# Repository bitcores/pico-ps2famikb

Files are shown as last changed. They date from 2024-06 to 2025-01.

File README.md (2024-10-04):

# pico-usb2famikb
Raspberry Pi Pico driven multi device emulator and Keyboard and Mouse Host for Famicom/NES by direct USB input or with an i2c host device

Emulates
* Family Basic Keyboard
* Subor Keyboard and Mouse
* Hori Track

And supports Keyboard and Mouse Host mode, a community developed serialized keyboard and mouse interface.

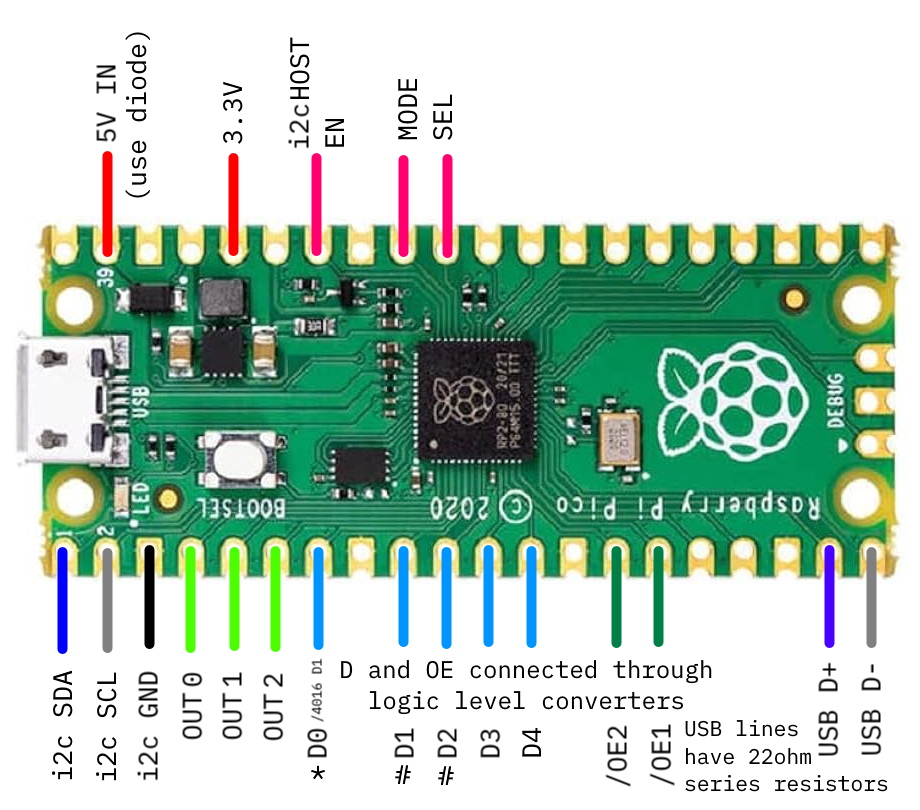
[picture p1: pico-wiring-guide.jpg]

- \* D0 is only needed for subor mouse support. Connecting it will conflict with controller 2, it can be left disconnected. 4016 D1 shares this pin, it is only needed for Hori Track support on Famicom.
- \# D1 and D2 are only needed for Family Basic Keyboard mode, these can be left disconnected (esp. if making for NES player 2 controller port)
- \? USB D+ and D- lines are only needed for direct input. These can be left disconnected if only the i2c Host will be used (i2c Host EN can then be tied to 3.3V to permanently enable it)
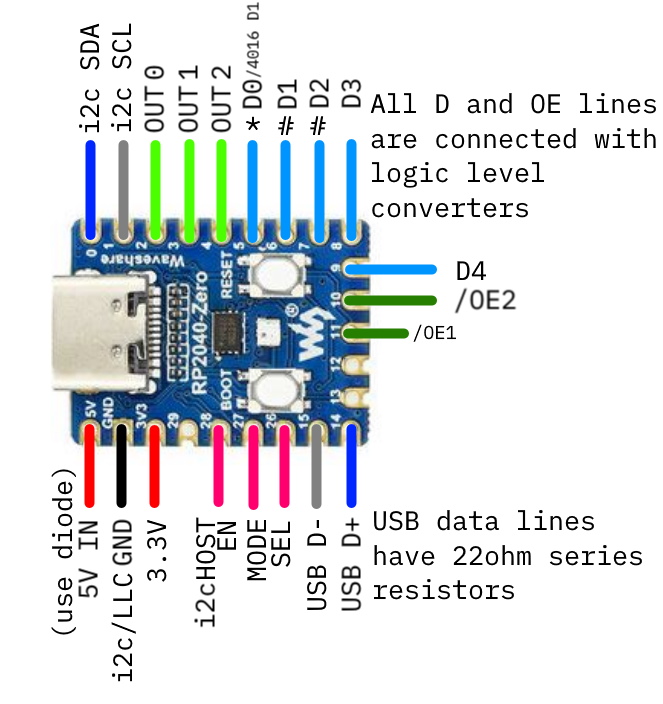
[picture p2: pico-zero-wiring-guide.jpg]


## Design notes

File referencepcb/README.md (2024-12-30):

# pico-usb2famikb Reference PCBs
This directory contains reference PCB designs for the pico-usb2famikb. They have not been designed by a experienced engineer, but they DO work.

If you have some experience designing circuits like this, I would very much welcome improved designs.

For the full featured reference design you will need:
* 1x Raspberry Pi Pico
* 1x diode (I am using a 1N5819)
* 1x push button
* 1x 15pin d-sub VGA connector (for expansion port)
* 1x USB A type female port
* 2x 22ohm resistors
* 1x 100uf 16v capacitor (input from console)
* 1x 330uf 16v capacitor
* 2x four-channel logic level converters
* 13x pin headers (and some jumpers)

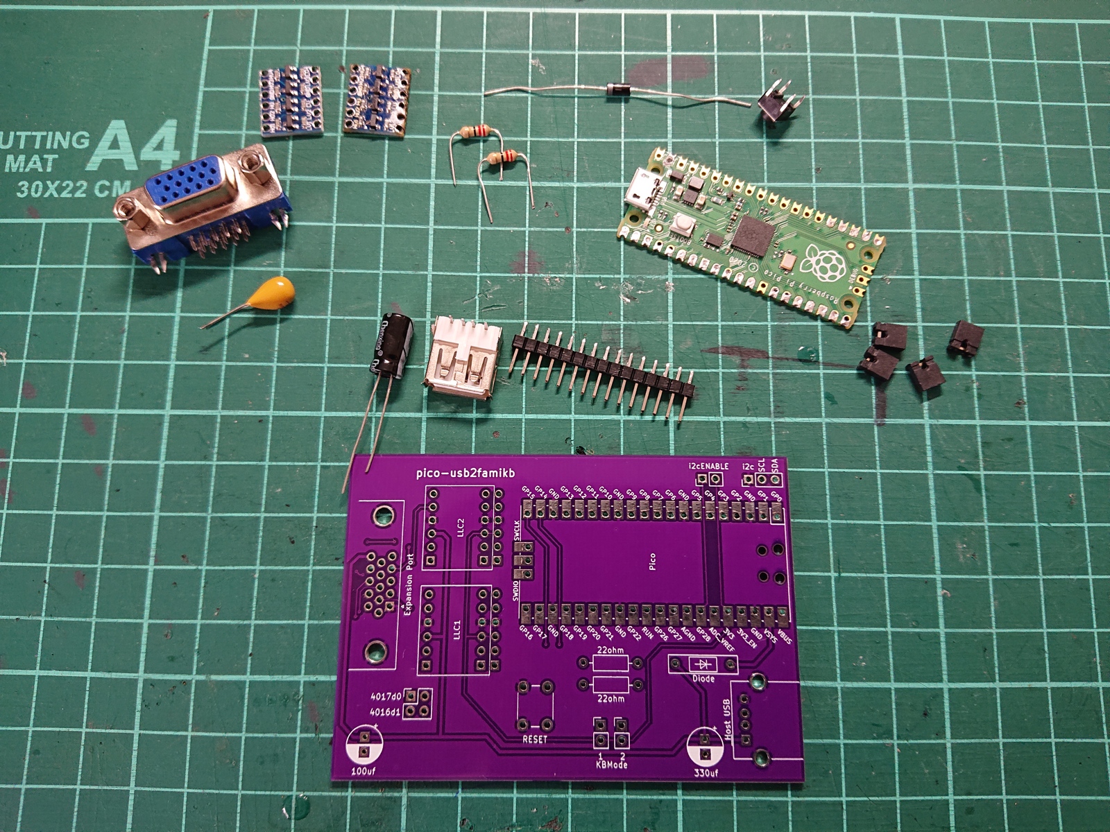
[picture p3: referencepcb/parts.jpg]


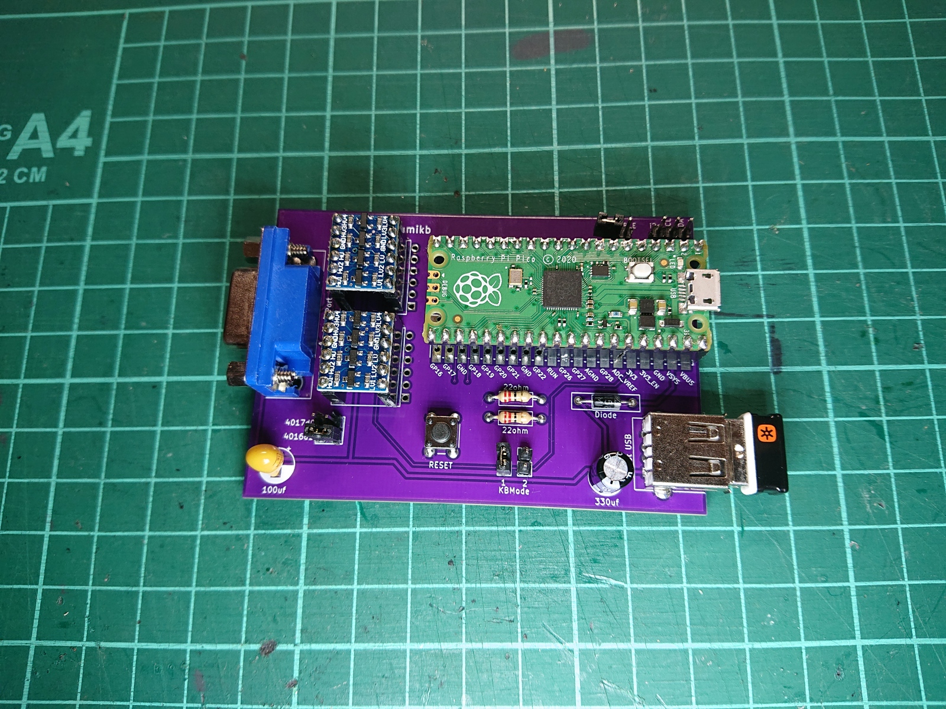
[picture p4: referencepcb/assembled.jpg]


Note: The 330uf capactior was added because some USB3 hubs seem to draw significant power on startup can could crash the console or Pico, or both. The USB2 hubs I tested don't seem affected, but you can also just plug everything in before you turn on the console to avoid any issues.

## Wiring guide
The expansion port connector is laid out as follows when viewed from the top.

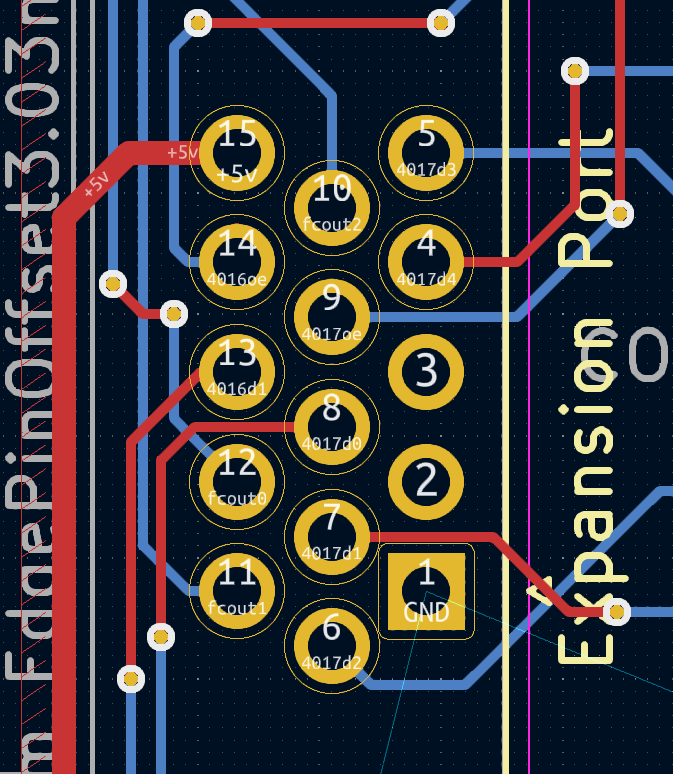
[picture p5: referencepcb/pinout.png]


It is wired following the pinout of the [Famicom Expansion Port](https://www.nesdev.org/wiki/Expansion_port), 01 to 01, 15 to 15.
Wiring for the NES is more complicated, please reference both the tables on that page for wiring.

## Jumper guide
### KB Mode
The pico-usb2famikb can operate in four different modes:
 - Keyboard Mouse Host
 - Family Basic Keyboard
 - Subor Keyboard and Mouse
 - Family Basic Keyboard and HoriTrack

These modes are selected by setting the KBMode jumpers before power on (or reset).

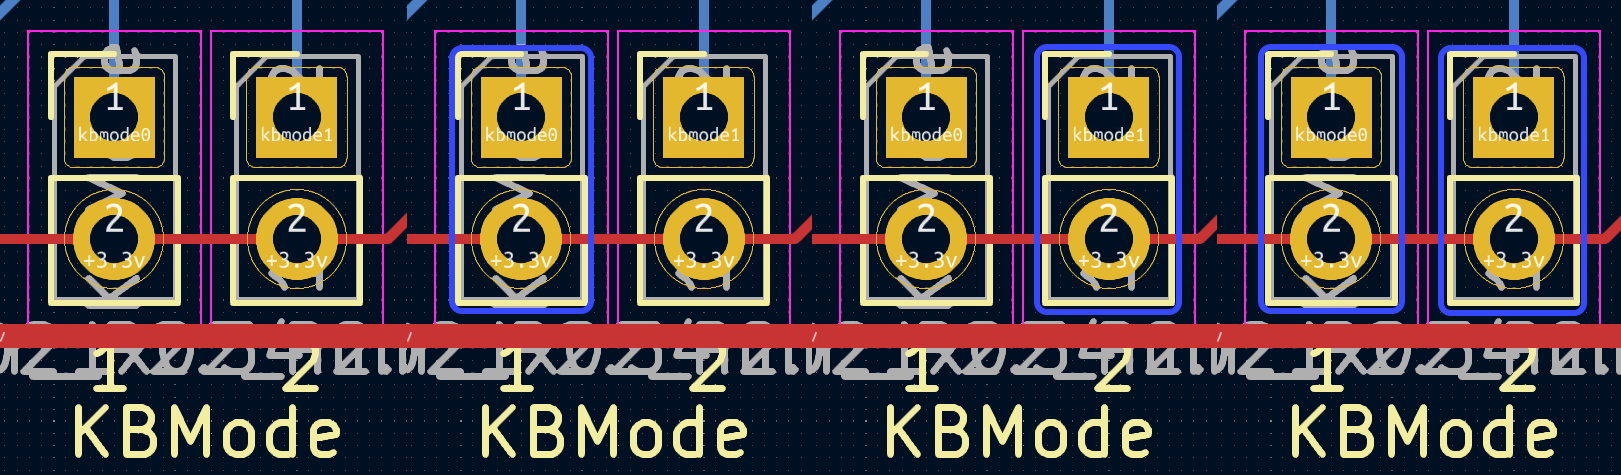
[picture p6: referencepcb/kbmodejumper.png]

 - No jumpers = Keyboard Mouse Host
 - One jumper on KBMode 1 = Family Basic Keyboard
 - One jumper on KBMode 2 = Subor Keyboard and Mouse
 - Two jumpers on KBMode 1 and 2 = Family Basic Keyboard and HoriTrack

### 4016D1/4017D0
HoriTrack and Subor Mouse require an extra data line which may interfere with controllers if left permanantly connected.

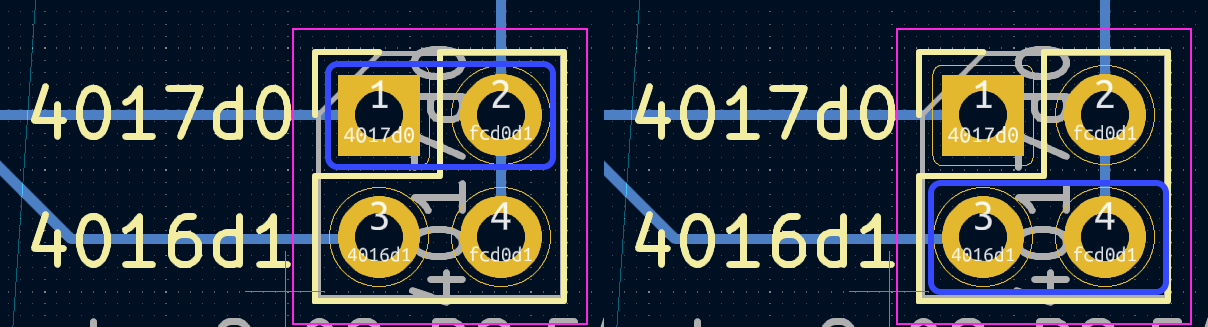
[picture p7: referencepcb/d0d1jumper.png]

 - 4017d0 for Subor Mouse
 - 4016d1 for HoriTrack

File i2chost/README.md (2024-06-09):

# pico-ps2famikb USB Host
This directory holds the software for running a USB Host for the pico-ps2famikb

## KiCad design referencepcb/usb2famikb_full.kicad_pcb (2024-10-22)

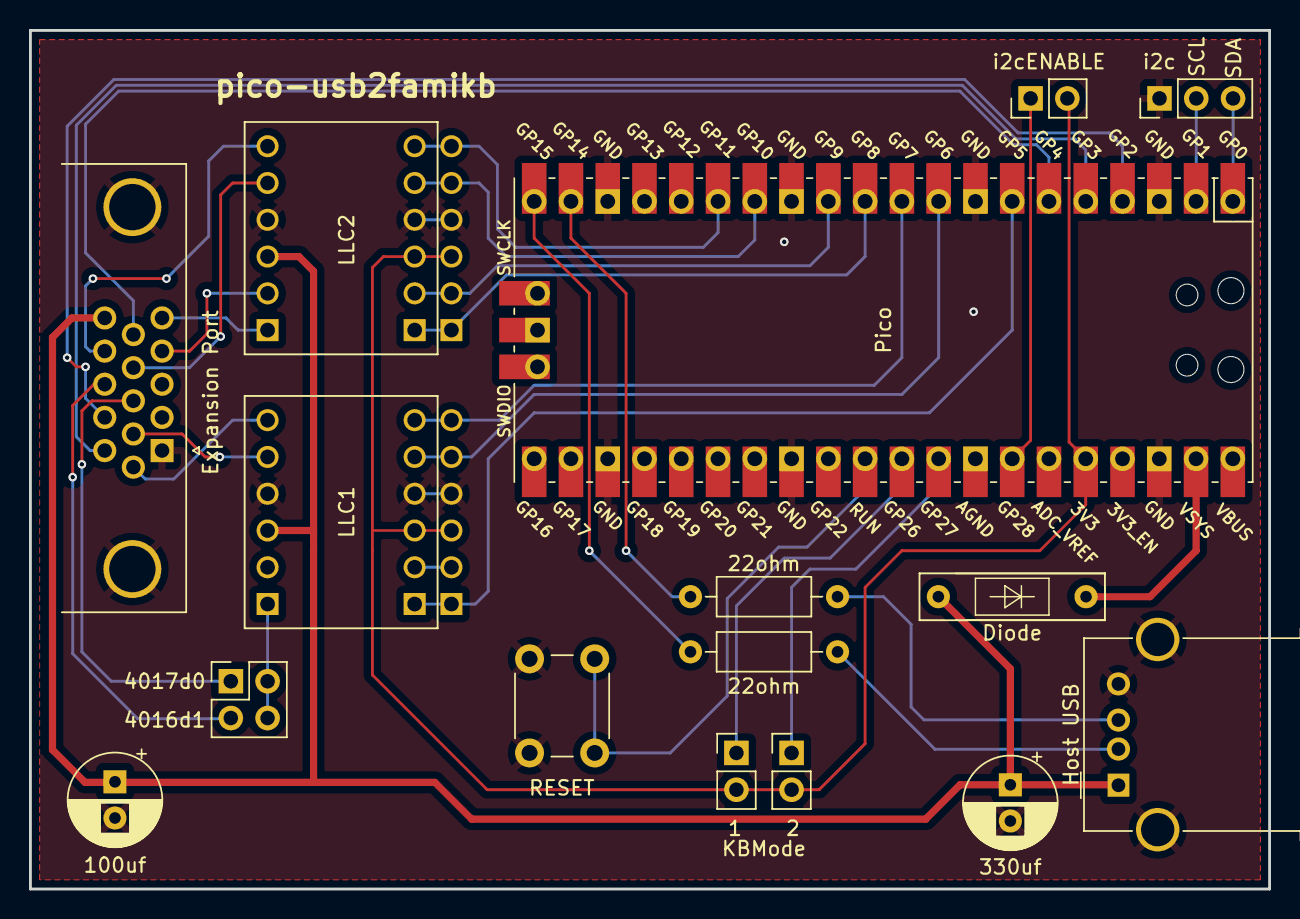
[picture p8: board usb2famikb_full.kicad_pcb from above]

Board: 2 copper layers, 85.6 x 59.3 mm, 16 parts (0 on the bottom side), 33 nets.

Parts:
1    2: PinHeader_1x02_P2.54mm_Vertical
22ohm, 22ohm#2: R_Axial_DIN0207_L6.3mm_D2.5mm_P10.16mm_Horizontal
100uf, 330uf: CP_Radial_D6.3mm_P2.50mm
4017d0: PinHeader_2x02_P2.54mm_Vertical
Diode: D_MELF-RM10_Universal_Handsoldering
Expansion Port: DSUB-15-HD_Female_Horizontal_P2.29x1.98mm_EdgePin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; DSUB-15-HD_Female_Horizontal_P2.29x1.98mm_EdgePinOffset3.03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
Host USB: USB_A_Molex_67643_Horizontal
KBMode: PinHeader_1x02_P2.54mm_Vertical
LLC1, LLC2: CONV_BOB-12009
Pico: RPi_Pico_SMD_TH
RESET: SW_PUSH_6mm
i2c: PinHeader_1x03_P2.54mm_Vertical
i2cENABLE: PinHeader_1x02_P2.54mm_Vertical

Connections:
4016d1: 4017d0.3, Expansion Port.13
4016oe: Expansion Port.14, LLC2.HV4
4017d0: 4017d0.1, Expansion Port.8
4017d1: Expansion Port.7, LLC1.HV3
4017d2: Expansion Port.6, LLC1.HV4
4017d3: Expansion Port.5, LLC2.HV1
4017d4: Expansion Port.4, LLC2.HV2
4017oe: Expansion Port.9, LLC2.HV3
+3.3v: 1 2.2, KBMode.2, LLC1.LV, LLC2.LV, Pico.36, i2cENABLE.2
+5v: 100uf.1, 330uf.1, Diode.2, Expansion Port.15, Host USB.1, LLC1.HV, LLC2.HV
GND: 100uf.2, 330uf.2, Expansion Port.0, Expansion Port.1, Host USB.4, Host USB.5, LLC1.GND_1, LLC1.GND_2, LLC2.GND_1, LLC2.GND_2, Pico.3, Pico.8, Pico.13, Pico.18, Pico.23, Pico.28, Pico.33, Pico.38, RESET.2, i2c.1
fcd0d1: 4017d0.2, 4017d0.4, LLC1.HV1
fcout0: Expansion Port.12, Pico.4
fcout1: Expansion Port.11, Pico.5
fcout2: Expansion Port.10, Pico.6
i2c1: Pico.1, i2c.3
i2c2: Pico.2, i2c.2
i2chosten: Pico.34, i2cENABLE.1
kbmode0: KBMode.1, Pico.31
kbmode1: 1 2.1, Pico.32
pico5v: Diode.1, Pico.39
pico4016oe: LLC2.LV4, Pico.15
pico4017d1: LLC1.LV3, Pico.9
pico4017d2: LLC1.LV4, Pico.10
pico4017d3: LLC2.LV1, Pico.11
pico4017d4: LLC2.LV2, Pico.12
pico4017oe: LLC2.LV3, Pico.14
pico_usb_d+: 22ohm.2, Pico.19
pico_usb_d-: 22ohm#2.2, Pico.20
picod0d1: LLC1.LV1, Pico.7
resetbtn: Pico.30, RESET.1
usb_d+: 22ohm.1, Host USB.3
usb_d-: 22ohm#2.1, Host USB.2

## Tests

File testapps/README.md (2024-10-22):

# pico-usb2famikb Test Applications
This directory contains test ROMs for the different modes the pico-usb2famikb can run under

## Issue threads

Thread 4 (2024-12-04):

Wiring and flashing firmware

k6lcm, 2024-12-04:
This is an awesome project! Thanks so much for documenting what you have designed. I was chatting with you over on needev.org but I figured it might make more sense to ask these questions here.

I have a North American NES and I am in the process of building up your board. I ordered the PCB from JLCPCB and they should be in soon. I have the expansion port exposed on my NES and I am 3D printing a connector that will hopefully (eventually) give me access to all of the pins in the expansion port.

I'm stumped as to next steps. Two things I can't figure out are:

1. Which pins on the NES expansion port should go to which pins on the VGA connector on your PCB design. Or ... should I just use the Player 2 Controller port?
2.  How do I actually write the code to the RPi Pico? I have flashed .uf2 firmware files to a Raspberry Pi Pico but I don't see such a file in your repo. Is there one? If not, how do I go about getting your code on the Pico?

Hoping to get this working so I can show it off at my display at Vintage Computer Fest SoCal in February! I think American in particular will be really excited to see a home-brew solution for getting a USB keyboard working on a North American NES, considering we always viewed the NES as strictly a games console and not a "computer."

bitcores, 2024-12-04:
The pinout for the VGA connector matches the [Famicom Expansion port](https://www.nesdev.org/wiki/Expansion_port).
The pinout is not super clear on the PCB, so here is an image labeling each hole on the board, looking at the top side.
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
You might be the first connecting it to an NES, so I can't be super clear about it. Whether you want to use the NES Expansion port or Controller Port 2 will depend on which modes you want to use.

If you want to support all the modes; Family Basic, Subor and Keyboard Mouse Host, you will need to connect to the Expansion port. If only the Keyboard Mouse Host then you can connect to the Controller Port 2.

The prebuilt .uf2 files are in the [Releases](https://github.com/bitcores/pico-ps2famikb/releases)

k6lcm, 2024-12-14:
I have it built an expansion port connector and fabricated your PCB with the Pi Pico. It is built up and connected from a USB keyboard to your PCB to the NES expansion port. The NES turns on but I can't seem to get any roms to recognize keyboard input. I'm wondering if I need to configure the jumpers correctly.

I see that there are jumpers for 4017d0 and 4016d1. In one of your [photos](
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
) you show a jumper on 4016d1.  I tried putting a jumper on 4016d1 or 4017d0 but no luck. Any ideas?

bitcores, 2024-12-14:
The jumper for 4017d0/4016d1 is for the subor mouse or Hori Track, so it isn't necessary for keyboard alone (I need to make a jumper guide, it is on my list of things to do).

Does the LED on the Pico turn on? I have that as an indicator of the Pico reaching the target overclock successfully. The overclock I have set is kinda near the limit without overvolting (perhaps too aggressive for the Pico W?) but I might be able to scale it back without affecting communication (another thing that was on my list of things to check).
If the LED isn't turning on, check that the Pico is getting power first, it can be plugged in directly if necessary (part of the reason for that diode). If it isn't a power issue, I'll try pulling back the overclock and release a build that might be compatible.

k6lcm, 2024-12-16:
I picked up a plain Pico (not W) just to eliminate that as a point of failure. I flashed the non-W Pico with your original firmware. The only jumper on the board are on KBmode 1.

However, I am still unable to get the keyboard test to recognize any USB keyboard input.

Is it normal when the system starts with the device connected, that the controllers in Player 1 and Player 2 do not work? The only way I can get the controllers to work is if I hold down the reset button, make a selection and then release. It is as if the board takes over the entire input system, blocking all other input.

bitcores, 2024-12-16:
"Is it normal when the system starts with the device connected, that the controllers in Player 1 and Player 2 do not work?"
It seems to vary from game to game. I just checked with Super Mario Bros and it seems to block all input, but with Ninja Gaiden it does not (perhaps because of reading Player 2 input?)

What software are you using to test it?  Thought I have not used it on real hardware, I would recommend [rainwarrior's](https://forums.nesdev.org/viewtopic.php?p=294558#p294558) test software. The KBMTEST program with no jumpers on KBmode should work.

k6lcm, 2024-12-19:
I am using a Pi Pico (not W) and your original firmware. But I must have something wrong, still.

I have tried two different USB keyboards but I am not getting any keypresses shown on the NES test ROM. Below is a numbered diagram showing how I have the VGA connector wired to the NES expansion port pins by number. Maybe you can do a quick sanity check for me to be sure I have the correct PINs matched between the NES and your board. Thanks for all if your help!
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

k6lcm, 2024-12-19:
I checked the pin connections and all are good to the motherboard. No jumpers on the board and LED on the Pi Pico is on when connected.

I might be getting warmer. I swapped around to a few more (older) USB keyboards. One of my oldest keyboards is giving some input but it is not correct. At least it is responding to keyboard input now, though.  I wish there was more contrast in the kbfami-24-04-22.nes test ROM. With no keys pressed, it appears in kbfami-24-04-22 as if a bunch of keys are mashed down.  However the difference between light grey and white is imperceptible in photos:
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

Using kbmhost here are some data points:

With the USB keyboard connected but no keys pressed:
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

And here it is with the number "1" key pressed:
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

There is a mouse cursor that seems to respond to the keyboard trackpad but it is erratic and does not respond in any usable way. Here is a clip:
https://github.com/user-attachments/assets/fb5be21e-a452-48f2-8379-1779d5e302c9

So I am getting some input but based on the feedback in kbfami-24-04-22 it appears mostly incorrect.

I took a look at rainwarrior's rom but it was source code. Do you have a compiled ROM for this? I wasn't able to get it compiled easily on my Mac.

bitcores, 2024-12-19:
Would you believe me if I told you that mouse movement looks correct?
When first developing the interface and the test app, I first implemented the absolute mouse positioning mode because it was easier to implement, but I never updated that test app for relative positioning so it would always rubberband back to 0,0. I have updated that now so it should work in both modes (you don't have to change anything on the interface) in kbmhost-24.12.20.nes
1E is the correct scancode for the "1" button being pressed, so there is that.  I also uploaded a build of rainwarrior's app into the testapps kbmtest.nes

I have also uploaded a newer build of the kbfami app that makes the text green, which may or may not be easier to pick up, but it includes display for subor keyboard as well, when the interface is in Family Basic Keyboard mode the keys should map to every second line of characters
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

To be clear:
With kbmtest.nes or kbmhost apps, have no jumpers on KBMode
With kbfami, have one jumper on KBMode 1
Be sure to reset the Pico when you change the KBMode jumpers, that setting is read on startup only.
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
k6lcm, 2025-01-17:
Thanks for this. I am learning Japanese, thanks to this project :-) Upon opening BASIC, it shows on screen in Japanese "connect the keyboard," right?
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

As soon as I drop in a jumper on KBMode 1 and reset the PCB, it loads! So clearly it is seeing the pico PCB as a Family BASIC keyboard. But still no response to key presses in BASIC either.
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

I'll keep monitoring this issue on GitHub. I'd love to be able to show off Family BASIC on an NES at VCF SoCal. The Apple I monitor is cool, too. Some people at the show will get it, but it is a little more obscure. Most everyone knows 10 PRINT "HELLO" most don't know what to do with an Apple I monitor, though.

Do you know of any NES/famicom programs that make use of the keyboard mode that is working with no jumpers for me? Also, would be great to have a cheat sheet for the various jumper configurations. I'm still not sure I understand them 100%.

bitcores, 2025-01-17:
I am somewhat at a loss as to why it won't work. The fact I don't have Family Basic to test it myself is a handicap to be sure, but the software I have that works with the Family Basic Keyboard in Mesen, works on the my Famicom with the interface.
I do have a few suggestions, though.

First, make sure you updated to that v1.0.2 release. Prior to that the interface wouldn't engage communications with already running software correctly (particularly because in my software and Family Basic the keyboard is never disabled, only on console power-on would it be flagged as disabled).

Secondly, I have noticed that presently the interface is sending the WRONG output when it thinks it is disabled. This will compound with the first point because Family Basic will think the keyboard is present while the interface thinks that it is disabled. I will fix that soon, but it shouldn't be an issue so long as you are using v1.0.2.

Thirdly, if you have an oscilloscope, even a cheap one, you can probe the OUT lines to see what sort of communication you are getting on them. OUT2 should be held at 5V, OUT1 should alternate between high and low about 9 times a set, OUT0 should have a single short peak but mostly be low. Anything different could be a connection issue, though problems on OUT0 and OUT1 should still result in output with some keys on the keyboard.

I don't know any other software that's using the Keyboard Mouse Host mode, it is relatively new in specification and in emulator and hardware support. KBMTest is probably the best to show it off because you get nice mouse display as well. Some of the Subor software is very glitchy from what I have seen and could be unreliable in demonstration (even in Mesen it didn't tend to work properly) and likely has the same problems as Family Basic Keyboard until we get that sorted out, but there is one feature that you could demonstrate with real software and that is the Hori Track emulation. U.S.Championship V'ball (JPN only?) has Hori Track support and if you put jumpers on KB Mode 1 AND 2, and 4016d1, then enable Trackball in the Configuration before starting a game you can control Player 1 with a mouse or other pointing device. You can see my demonstration of it here [https://youtu.be/MHf1rcq8KoE?t=306](https://youtu.be/MHf1rcq8KoE?t=306)

k6lcm, 2025-01-17:
You did it! I thought I had updated to v1.0.2 yesterday but I hadn't actually flashed the Pico. Once I updated, Family BASIC started working!

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

You still must hold down reset in order to give control to the joypad but that's fine. Once I'm in BASIC, I can actually use it! This will be a ton of fun at the show. Thanks! I'm going to direct people to your work if they are interested in learning more!

bitcores, 2025-01-18:
That's great!
Regarding having to hold reset, I think that is also a result of the interface sending the wrong output when the keyboard is disabled so should be fixed in the next release. Keep a look out for v1.0.3
I think I may have to slightly remap keys for Family Basic Keyboard so that it is more accessible on US keyboards and make a cheatsheet for that as well.

k6lcm, 2025-01-18:
That all makes sense. I figured out that shift-2 was " (just like on the Commodore 64) but I'm sure there are other characters that I won't be so lucky with. Good luck and let me know if I can test anything else. I think we can close this issue! Thanks again!

Closed 2025-01-18.

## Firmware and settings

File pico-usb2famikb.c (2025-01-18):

/* Copyright (C) 1883 Thomas Edison - All Rights Reserved
 * You may use, distribute and modify this code under the
 * terms of the GPLv2 license, which unfortunately won't be
 * written for another century.
 *
 * SPDX-License-Identifier: GPL-2.0-or-later
 */
#pragma GCC push_options
#pragma GCC optimize("-O3")

#include <stdlib.h>
#include <stdio.h>
#include <string.h>
#include <hardware/i2c.h>
#include <pico/i2c_slave.h>

#include "pico/bootrom.h"
#include "pico/stdlib.h"
#include "pico/multicore.h"
#include "hardware/clocks.h"
#include "hardware/gpio.h"
#include "hardware/pio.h"
#include "hardware/irq.h"

#ifdef CYW43_WL_GPIO_LED_PIN
#include "pico/cyw43_arch.h"
#endif

#include "pio_usb.h"
#include "tusb.h"

#include "neskbdinter.h"
#include "usb2famikb.h"

// unnecessary now?
//#include "kblayout.c"

// $4016 "out" from Famicom/NES, three consecutive pins
#define NES_OUT 2
// $4017 OE $4017 strobe read
#define NES_JOY2OE 10
// $4016 OE $4016 strobe read
#define NES_JOY1OE 11
// $4017 "data" lines, five consecutive pins
#define NES_DATA 5

// I2C communication pins
#define I2C_SDA_PIN 0
#define I2C_SCL_PIN 1

// keyboard mode select, two consecutive pins
#define KB_MODE 26

// direct input or i2chost select
#define i2cHOST_ENABLE 28


#define MAX_BUFFER 16
#define WORD_SIZE 4

// extra config for devices in direct input mode
#define MSERELATIVE 1
#define HORILHAND 1
#define HORILOWSPD 0
#define SENDREPEATS 1


// configuration for PIO USB
// DPDM configuration D+ = pin 14, D- = pin 15
// configure used SMs around currently used SMs
// use pio1, it has available SMs
// dp pin, usb tx pio, usb tx sm, usb tx dma
// usb rx pio, usb rx sm, usb eop sm
#define PIO_USB_CONFIG                                                          \
    {                                                                           \
        14, 1, 0, 0,                                                            \
            1, 1, 2,                                                            \
            NULL, PIO_USB_DEBUG_PIN_NONE,                                       \
            PIO_USB_DEBUG_PIN_NONE, false, PIO_USB_PINOUT_DPDM                  \
    }


// keypress matrix for family basic mode & suborkb
static bool keymatrix[] = {
    0, 0, 0, 0, 0, 0, 0, 0, // 0 0, 0 1
    0, 0, 0, 0, 0, 0, 0, 0, // 1 0, 1 1
    0, 0, 0, 0, 0, 0, 0, 0, // 2 0, 2 1
    0, 0, 0, 0, 0, 0, 0, 0, // 3 0, 3 1
    0, 0, 0, 0, 0, 0, 0, 0, // 4 0, 4 1
    0, 0, 0, 0, 0, 0, 0, 0, // 5 0, 5 1
    0, 0, 0, 0, 0, 0, 0, 0, // 6 0, 6 1
    0, 0, 0, 0, 0, 0, 0, 0, // 7 0, 7 1
    0, 0, 0, 0, 0, 0, 0, 0, // 8 0, 8 1 famikb stops here
    0, 0, 0, 0, 0, 0, 0, 0, // 9 0, 9 1
    0, 0, 0, 0, 0, 0, 0, 0, // 10 0, 10 1
    0, 0, 0, 0, 0, 0, 0, 0, // 11 0, 11 1
    0, 0, 0, 0, 0, 0, 0, 0  // 12 0, 12 1
};
static const uint8_t famikey[] = {
    KEY_RIGHTBRACE, KEY_LEFTBRACE, KEY_ENTER, KEY_F8, 
    KEY_F12, KEY_BACKSLASH, KEY_RIGHTSHIFT, KEY_RIGHTALT,
    KEY_SEMICOLON, KEY_APOSTROPHE, KEY_DELETE, KEY_F7, // APOSTROPHE maps to COLON
    KEY_EQUAL, KEY_MINUS, KEY_SLASH, KEY_RIGHTCTRL,
    KEY_K, KEY_L, KEY_O, KEY_F6,
    KEY_0, KEY_P, KEY_COMMA, KEY_DOT,
    KEY_J, KEY_U, KEY_I, KEY_F5,
    KEY_8, KEY_9, KEY_N, KEY_M,
    KEY_H, KEY_G, KEY_Y, KEY_F4,
    KEY_6, KEY_7, KEY_V, KEY_B,
    KEY_D, KEY_R, KEY_T, KEY_F3,
    KEY_4, KEY_5, KEY_C, KEY_F,
    KEY_A, KEY_S, KEY_W, KEY_F2,
    KEY_3, KEY_E, KEY_Z, KEY_X,
    KEY_LEFTCTRL, KEY_Q, KEY_ESC, KEY_F1,
    KEY_2, KEY_1, KEY_LEFTALT, KEY_LEFTSHIFT,
    KEY_LEFT, KEY_RIGHT, KEY_UP, KEY_HOME,
    KEY_INSERT, KEY_BACKSPACE, KEY_SPACE, KEY_DOWN
};
static const uint8_t suborkey[] = {
    KEY_C, KEY_F, KEY_G, KEY_4,
    KEY_V, KEY_5, KEY_E, KEY_F2,
    KEY_END, KEY_S, KEY_D, KEY_2,
    KEY_X, KEY_3, KEY_W, KEY_F1,
    KEY_RIGHT, KEY_PAGEDOWN, KEY_BACKSPACE, KEY_INSERT, 
    KEY_HOME, KEY_DELETE, KEY_PAGEUP, KEY_F8,
    KEY_COMMA, KEY_L, KEY_I, KEY_9, 
    KEY_DOT, KEY_0, KEY_O, KEY_F5, 
    KEY_LEFT, KEY_UP, KEY_ENTER, KEY_RIGHTBRACE, 
    KEY_DOWN, KEY_BACKSLASH, KEY_LEFTBRACE, KEY_F7, 
    KEY_TAB, KEY_Z, KEY_CAPSLOCK, KEY_Q,  
    KEY_LEFTCTRL, KEY_1, KEY_A, KEY_ESC, 
    KEY_M, KEY_K, KEY_Y, KEY_7, 
    KEY_J, KEY_8, KEY_U, KEY_F4,  
    KEY_SLASH, KEY_APOSTROPHE, KEY_SEMICOLON, KEY_MINUS, 
    KEY_LEFTSHIFT, KEY_EQUAL, KEY_P, KEY_F6, 
    KEY_SPACE, KEY_N, KEY_H, KEY_T,
    KEY_B, KEY_6, KEY_R, KEY_F3, 
    KEY_KP8, KEY_KP4, KEY_KPENTER, KEY_KP6,
    0x00, 0x00, 0x00, KEY_KP2, // this is odd, verify
    KEY_F11, KEY_KP7, KEY_KP4, KEY_LEFTALT, 
    KEY_KP8, KEY_KP2, KEY_KP1, KEY_F12, 
    KEY_KP9, KEY_KPASTERISK, KEY_KPPLUS, KEY_KPMINUS, 
    KEY_NUMLOCK, KEY_KPSLASH, KEY_KP5, KEY_F10,  
    KEY_SPACE, KEY_PAUSE, KEY_KP6, KEY_GRAVE,
    KEY_KP0, KEY_KPDOT, KEY_KP3, KEY_F9 
};
static const uint8_t modkeys[] = { 
    KEY_LEFTCTRL, KEY_LEFTSHIFT, KEY_LEFTALT, KEY_LEFTMETA,
    KEY_RIGHTCTRL, KEY_RIGHTSHIFT, KEY_RIGHTALT, KEY_RIGHTMETA
};


// Just use a 6 byte memory array for storing the latest data for the mouse
static struct
{
    uint8_t mem[6];
    uint8_t mem_address;
    bool mem_address_written;
    bool garbage_message;
} hostmsg;

static bool new_input_msg;
// FIFO buffer for keypresses for standard mode
// buffer length will be relatively small because under standard operation
// the NES is likely to be reading from the buffer very frequently
static uint8_t bufferindex = 0;
static uint8_t keybuffer[MAX_BUFFER];
static uint8_t kbbbindex = 0;
static uint8_t kbbackbuffer[MAX_BUFFER];
// transport buffer index
static uint8_t transbbindex = 0;
// mouse updates won't be buffered like the keyboard, if multiple updates come
// inbetween a frame, we want to put them together instead of stack them up
// oversizing the buffer type to mitigate overflow
static int16_t msebuffer[4];
// we want to store 
static int16_t mseinstbuf[4];
static int8_t mousex;
static int8_t mousey;

static bool NESinlatch = false;

static uint8_t usb2kbmode;
static bool i2chostmode = false;

static uint32_t output = 0;
static uint8_t select = 0;
static uint8_t enable = 0;
static uint8_t toggle = 0;
static bool instrobe = false;

static uint32_t kbword = 0;
static uint32_t mseword = 0;

static uint8_t subormouse[4]; // three byte holder for subor mouse data (one byte pad)
static uint8_t sbmouseindex = 0;
static uint8_t sbmouselength = 0; // should be 1 or 3 each report
static uint32_t horitrack = 0; // output data for horitrack


// https://github.com/raspberrypi/pico-examples/blob/master/blink/blink.c
// Perform initialisation
int pico_led_init(void) {
#if defined(PICO_DEFAULT_LED_PIN)
    // A device like Pico that uses a GPIO for the LED will define PICO_DEFAULT_LED_PIN
    // so we can use normal GPIO functionality to turn the led on and off
    gpio_init(PICO_DEFAULT_LED_PIN);
    gpio_set_dir(PICO_DEFAULT_LED_PIN, GPIO_OUT);
    return PICO_OK;
#elif defined(CYW43_WL_GPIO_LED_PIN)
    // For Pico W devices we need to initialise the driver etc
    return cyw43_arch_init();
#endif
}

// Turn the led on or off
void pico_set_led(bool led_on) {
#if defined(PICO_DEFAULT_LED_PIN)
    // Just set the GPIO on or off
    gpio_put(PICO_DEFAULT_LED_PIN, led_on);
#elif defined(CYW43_WL_GPIO_LED_PIN)
    // Ask the wifi "driver" to set the GPIO on or off
    cyw43_arch_gpio_put(CYW43_WL_GPIO_LED_PIN, led_on);
#endif
}
// -----------------------------------------------------------

// handle key input into the buffer or matrices
static void keycode_handler(uint8_t ascii) {
    bool release;
    if (usb2kbmode > 0) {
        release = (ascii >> 7) ? 0: 1;
        ascii = ascii & 127;
    }

    if (usb2kbmode == 1 || usb2kbmode == 3) { // famikey modes
        // update the status of the key
        for (uint8_t i = 0; i < sizeof(famikey); i++) {
            if (famikey[i] == ascii) {
                keymatrix[i] = release;
                break;
            }
        }
    } else if (usb2kbmode == 2) { // subor mode
        // update the status of the key
        for (uint8_t i = 0; i < sizeof(suborkey); i++) {
            if (suborkey[i] == ascii) {
                keymatrix[i] = release;
                // some keys appear more than once in the matrix
                //break;
            }
        }
    } else { // keyboard mouse host mode
        if ((bufferindex+1) == MAX_BUFFER) {
            for (int i = 1; i < MAX_BUFFER; i++) {
                keybuffer[i-1] = keybuffer[i];
            }
            keybuffer[bufferindex] = ascii;
        }
        else {
            keybuffer[bufferindex] = ascii;
            bufferindex++;
        }
    }

}

// I2C configuration
static const uint I2C_ADDRESS = 0x17;
static const uint I2C_BAUDRATE = 100000; // 100 kHz
// Our handler is called from the I2C ISR, so it must complete quickly. Blocking calls /
// printing to stdio may interfere with interrupt handling.
static void i2c_slave_handler(i2c_inst_t *i2c, i2c_slave_event_t event) {
    switch (event) {
    case I2C_SLAVE_RECEIVE: // master has written some data
        if (!hostmsg.mem_address_written) {
            // writes always start with the memory address
            // the first value here is a len, ignore
            hostmsg.mem_address = i2c_read_byte_raw(i2c);
            // host should always address addr 0 in the buffer
            if (hostmsg.mem_address != 0){
                hostmsg.garbage_message = true;
            } else {
                hostmsg.garbage_message = false;
            }
            hostmsg.mem_address_written = true;
        } else {
            // if it is garbage we just read the values
            // but don't put them in memory
            if (hostmsg.garbage_message) {
                i2c_read_byte_raw(i2c);
            }
            else { // put thew values into buffer
                hostmsg.mem[hostmsg.mem_address] = i2c_read_byte_raw(i2c);
                hostmsg.mem_address = (hostmsg.mem_address + 1) % 6;
            }
        }
        break;
    case I2C_SLAVE_REQUEST: // master is requesting data
        // load from memory
        i2c_write_byte_raw(i2c, hostmsg.mem[hostmsg.mem_address]);
        hostmsg.mem_address = (hostmsg.mem_address + 1) % 6;
        break;
    case I2C_SLAVE_FINISH: // master has signalled Stop / Restart
        if (!hostmsg.garbage_message) {
            // parse the value from mem[1] if not 0x00
            if (hostmsg.mem[1] != 0x00) {
                keycode_handler(hostmsg.mem[1]);
            }
            // only update mouse buffer if mouse is "present"
            if ((hostmsg.mem[2] & 32) == 32) {
                // and the first byte with the current value
                // this means if a button is pressed, it will stay "pressed"
                // until the NES polls it (probably next frame)
                msebuffer[0] |= hostmsg.mem[2];
                // if true, we are in relative mode
                if ((msebuffer[0] & 8) == 8 && new_input_msg) {
                    msebuffer[1] += (int8_t)hostmsg.mem[3];
                    msebuffer[2] += (int8_t)hostmsg.mem[4];
                } else {
                    msebuffer[1] = (int8_t)hostmsg.mem[3];
                    msebuffer[2] = (int8_t)hostmsg.mem[4];   
                }
                // some wheel movements or middle button events could
                // be missed. target for improvement later
                msebuffer[3] |= hostmsg.mem[5];
            }
            new_input_msg = true;
        }
        
        hostmsg.mem_address_written = false;
        
        break;
    default:
        break;
    }
}

// when mouse data is sent to the NES, update relevant buffer data
static void update_mouse_data() {
    // if there is new data from the host
    if (new_input_msg) {
        if (i2chostmode) {
            // actually update button values
            msebuffer[0] = hostmsg.mem[2];
            msebuffer[3] = hostmsg.mem[5];
        } else {
            msebuffer[0] = mseinstbuf[0];
            msebuffer[1] = mseinstbuf[1];
            msebuffer[2] = mseinstbuf[2];
            msebuffer[3] = mseinstbuf[3] & 0x87;
        }
        new_input_msg = false;
    }
}

// IRQ handler for OE lines to shift data
void pio_IRQ_handler() {

    if (pio_interrupt_get(pio0, 3)) {
        if (usb2kbmode == 2) {
            // move the subor mouse data along
            subormouse[sbmouseindex] = subormouse[sbmouseindex] << 1;
        }
        else if (usb2kbmode == 0) {
            mseword = mseword << 1;
            kbword = kbword << 1;
        }
        else if (usb2kbmode == 3) {
            horitrack = horitrack << 1;
        }

        pio_interrupt_clear(pio0, 3);
    }
}
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
int main() {
    // need a clock speed that is a multiple of 12,000
    //set_sys_clock_khz(264000, true);
    set_sys_clock_khz(216000, true);

    //  configure pico-ps2kb based on gpio
    gpio_init(KB_MODE); gpio_init(KB_MODE+1);
    gpio_set_dir(KB_MODE, GPIO_IN); gpio_set_dir(KB_MODE+1, GPIO_IN);
    gpio_pull_down(KB_MODE); gpio_pull_down(KB_MODE+1);

    //  0: serialized mode
    //  1: famikb mode
    //  2: subor mode
    //  3: famikb+hori trackball
    usb2kbmode |= gpio_get(KB_MODE+1) << 1;
    usb2kbmode |= gpio_get(KB_MODE);

    gpio_init(i2cHOST_ENABLE);
    gpio_set_dir(i2cHOST_ENABLE, GPIO_IN);
    gpio_pull_down(i2cHOST_ENABLE);
    
    i2chostmode = gpio_get(i2cHOST_ENABLE);

    // prepare buffers
    for (int i = 0; i < MAX_BUFFER; i++) {
        keybuffer[i] = 0x00;
    }
    for (int i = 1; i < 4; i++) {
        msebuffer[i] = 0x00;
        subormouse[i-1] = 0x00;
        mseinstbuf[i] = 0x00;
    }
    // set only the device id in the buffer so if the NES
    // strobes for update before data received it will know
    // the interface is present
    msebuffer[0] = mseinstbuf[0] = 0x06;

    multicore_reset_core1();
    //  run the NES handler on seperate core
    multicore_launch_core1(nes_handler_thread);

    // turn on LED to show device has booted fine
    pico_led_init();
    pico_set_led(true);

    if (i2chostmode) {
        gpio_init(I2C_SDA_PIN);
        gpio_set_function(I2C_SDA_PIN, GPIO_FUNC_I2C);
        gpio_pull_up(I2C_SDA_PIN);

        gpio_init(I2C_SCL_PIN);
        gpio_set_function(I2C_SCL_PIN, GPIO_FUNC_I2C);
        gpio_pull_up(I2C_SCL_PIN);

        
        i2c_init(i2c0, I2C_BAUDRATE);
        // configure I2C0 for slave mode
        i2c_slave_init(i2c0, I2C_ADDRESS, &i2c_slave_handler);

        // loop forever now
        for (;;) {
            if ((transbbindex != kbbbindex) && !NESinlatch){
                // if the buffer is full, don't do anything yet
                if ((bufferindex+1) < MAX_BUFFER) {
                    keybuffer[bufferindex] = kbbackbuffer[transbbindex];
                    bufferindex++;

                    transbbindex = (transbbindex + 1) % MAX_BUFFER;
                } 
            }
            // gets a little ansy without a little sleep here
            sleep_ms(1);
        }
        
    }
    else {
        mseinstbuf[0] |= MSERELATIVE << 3;
        sleep_ms(10);

        // Use tuh_configure() to pass pio configuration to the host stack
        // Note: tuh_configure() must be called before
        pio_usb_configuration_t pio_cfg = PIO_USB_CONFIG;
        tuh_configure(1, TUH_CFGID_RPI_PIO_USB_CONFIGURATION, &pio_cfg);

        // To run USB SOF interrupt in core0, init host stack for pio_usb (roothub
        // port1) on core0
        tuh_init(1);

        /*if (tuh_inited()) {
            sleep_ms(500);
            gpio_put(LED_PIN, 0);
            sleep_ms(500);
            gpio_put(LED_PIN, 1);
        }*/

        while (true) {
            tuh_task(); // tinyusb host task
        }
    }

}

//--------------------------------------------------------------------+
// Host HID
//--------------------------------------------------------------------+

// Invoked when device with hid interface is mounted
// Report descriptor is also available for use. tuh_hid_parse_report_descriptor()
// can be used to parse common/simple enough descriptor.
// Note: if report descriptor length > CFG_TUH_ENUMERATION_BUFSIZE, it will be skipped
// therefore report_desc = NULL, desc_len = 0
void tuh_hid_mount_cb(uint8_t dev_addr, uint8_t instance, uint8_t const* desc_report, uint16_t desc_len)
{
    (void)desc_report;
    (void)desc_len;

    // Interface protocol (hid_interface_protocol_enum_t)
    uint8_t const itf_protocol = tuh_hid_interface_protocol(dev_addr, instance);

    // Receive report from boot keyboard & mouse only
    // tuh_hid_report_received_cb() will be invoked when report is available
    if (itf_protocol == HID_ITF_PROTOCOL_KEYBOARD || itf_protocol == HID_ITF_PROTOCOL_MOUSE) {
        switch (itf_protocol) {
            case (HID_ITF_PROTOCOL_KEYBOARD):
                mseinstbuf[0] |= 0x10;
                break;
            case (HID_ITF_PROTOCOL_MOUSE):
                mseinstbuf[0] |= 0x20;
                break;
        }
        new_input_msg = true;

        //  set up report receiving
        tuh_hid_receive_report(dev_addr, instance);

    }
}

// Invoked when device with hid interface is un-mounted
void tuh_hid_umount_cb(uint8_t dev_addr, uint8_t instance)
{
    uint8_t const itf_protocol = tuh_hid_interface_protocol(dev_addr, instance);
    
    switch (itf_protocol) {
        case (HID_ITF_PROTOCOL_KEYBOARD):
            mseinstbuf[0] &= 0xEF;
            break;
        case (HID_ITF_PROTOCOL_MOUSE):
            mseinstbuf[0] &= 0xDF;
            break;
    }
    new_input_msg = true;
}

// look up new key in previous keys
static inline bool find_key_in_report(hid_keyboard_report_t const *report, uint8_t keycode)
{
    for(uint8_t i=0; i<6; i++) {
        if (report->keycode[i] == keycode)  return true;
    }

    return false;
}

// check if a keycode is missing from prev report
static inline void find_releases_in_report(hid_keyboard_report_t const *prev_report, hid_keyboard_report_t const *report)
{
    for(uint8_t i=0; i<6; i++)
    {
        if (prev_report->keycode[i] == 0x00) { break; }
        if (prev_report->keycode[i] != report->keycode[i]) {
            keycode_handler(prev_report->keycode[i] + 0x80);
            break;
        }
    }
}

// check if modifier keys have changed
static inline void update_modifiers(hid_keyboard_report_t const *prev_report, hid_keyboard_report_t const *report)
{
    uint8_t c = 1;
    for(uint8_t i=0; i<8; i++)
    {
        if ((prev_report->modifier & c) != (report->modifier & c)){
            if ((report->modifier & c) == 0){ // modifier released
                keycode_handler(modkeys[i] + 0x80);
            } else {
                keycode_handler(modkeys[i]);
            }
        }
        c <<= 1;
    }
}

// process the kbd report and send to keycode handler
static void process_kbd_report(hid_keyboard_report_t const *report)
{
    static hid_keyboard_report_t prev_report = { 0, 0, {0} }; // previous report to check key released

    // keycode positions change when released, so need to check all
    find_releases_in_report(&prev_report, report);
    // check if modifier keys have changed
    update_modifiers(&prev_report, report);

    for(uint8_t i=0; i<6; i++)
    {
        uint8_t keycode = report->keycode[i];
        if ( keycode )
        {
            if (find_key_in_report(&prev_report, keycode)) {
                // ignore for now would like a repeat thing
            } else {
                keycode_handler(keycode);
            }
        }
    }

    prev_report = *report;
}

// process the mouse report and insert into buffers
static void process_mouse_report(hid_mouse_report_t const *report)
{
    uint8_t temp = mseinstbuf[0] & 0x3F;
    temp |= (report->buttons & MOUSE_BUTTON_LEFT) << 7;
    temp |= (report->buttons & MOUSE_BUTTON_RIGHT) << 5;
    mseinstbuf[0] = temp;
    msebuffer[0] |= mseinstbuf[0];

    temp = 0x00;
    temp |= (report->buttons & MOUSE_BUTTON_MIDDLE) << 5;
    temp |= (report->wheel & 0x0F) << 3;
    temp |= HORILHAND << 1;
    temp |= HORILOWSPD;
    mseinstbuf[3] = temp;
    msebuffer[3] |= mseinstbuf[3];

    if (MSERELATIVE) {
        if (new_input_msg) {
            msebuffer[1] += report->x;
            msebuffer[2] += report->y;
            mseinstbuf[1] = report->x;
            mseinstbuf[2] = report->y;
        } else {
            msebuffer[1] = mseinstbuf[1] = report->x;
            msebuffer[2] = mseinstbuf[2] = report->y;
        }
    } else {
        mseinstbuf[1] += report->x;
        if (mseinstbuf[1] < 0) { mseinstbuf[1] = 0; }
        if (mseinstbuf[1] > 255) { mseinstbuf[1] = 255; }

        mseinstbuf[2] += report->y;
        if (mseinstbuf[2] < 0) { mseinstbuf[2] = 0; }
        if (mseinstbuf[2] > 255) { mseinstbuf[2] = 255; }
        
        msebuffer[1] = mseinstbuf[1];
        msebuffer[2] = mseinstbuf[2];
    }

    new_input_msg = true;

}
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

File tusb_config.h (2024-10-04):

/*
 * The MIT License (MIT)
 *
 * Copyright (c) 2019 Ha Thach (tinyusb.org)
 *
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
 */

#ifndef _TUSB_CONFIG_H_
#define _TUSB_CONFIG_H_

#ifdef __cplusplus
 extern "C" {
#endif

//--------------------------------------------------------------------
// COMMON CONFIGURATION
//--------------------------------------------------------------------

#define CFG_TUSB_OS               OPT_OS_PICO

// Enable device stack
#define CFG_TUD_ENABLED     0

// Enable host stack with pio-usb if Pico-PIO-USB library is available
#define CFG_TUH_ENABLED     1
#define CFG_TUH_RPI_PIO_USB 1

// CFG_TUSB_DEBUG is defined by compiler in DEBUG build
// #define CFG_TUSB_DEBUG           0

/* USB DMA on some MCUs can only access a specific SRAM region with restriction on alignment.
 * Tinyusb use follows macros to declare transferring memory so that they can be put
 * into those specific section.
 * e.g
 * - CFG_TUSB_MEM SECTION : __attribute__ (( section(".usb_ram") ))
 * - CFG_TUSB_MEM_ALIGN   : __attribute__ ((aligned(4)))
 */
#ifndef CFG_TUSB_MEM_SECTION
#define CFG_TUSB_MEM_SECTION
#endif

#ifndef CFG_TUSB_MEM_ALIGN
#define CFG_TUSB_MEM_ALIGN          __attribute__ ((aligned(4)))
#endif

//--------------------------------------------------------------------
// DEVICE CONFIGURATION
//--------------------------------------------------------------------

#ifndef CFG_TUD_ENDPOINT0_SIZE
#define CFG_TUD_ENDPOINT0_SIZE    64
#endif

//------------- CLASS -------------//
#define CFG_TUD_CDC              1

// CDC FIFO size of TX and RX
#define CFG_TUD_CDC_RX_BUFSIZE   256
#define CFG_TUD_CDC_TX_BUFSIZE   256

// CDC Endpoint transfer buffer size, more is faster
#define CFG_TUD_CDC_EP_BUFSIZE   64

//--------------------------------------------------------------------
// HOST CONFIGURATION
//--------------------------------------------------------------------

// Size of buffer to hold descriptors and other data used for enumeration
#define CFG_TUH_ENUMERATION_BUFSIZE 256

#define CFG_TUH_HUB                 1
// max device support (excluding hub device)
#define CFG_TUH_DEVICE_MAX          (CFG_TUH_HUB ? 4 : 1) // hub typically has 4 ports

#define CFG_TUH_HID                  4
#define CFG_TUH_HID_EPIN_BUFSIZE    64
#define CFG_TUH_HID_EPOUT_BUFSIZE   64

#ifdef __cplusplus
 }
#endif

#endif /* _TUSB_CONFIG_H_ */

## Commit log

2024-04-03 sample build file from current code
2024-05-11 add schematic
    a semi reference schematic, work on progress
2024-06-05 prepare for i2c
    rearrangement of pins with preparation for i2c usb host support
2024-06-09 usbhost support
    usbhost support added via i2c
2024-06-16 usbhost full implement
    The USBHost mode is now fully implemented with support for remapping on the host side, relative mode for mouse cursor movement, mouse wheel and middle button.
    It may be possible to lose some events on the mouse wheel and/or middle button, this could be fixed later.
    Also included wiring guides for Pico and Pico-Zero.
2024-06-23 prevent buffer overrun
    prevent buffer overrunning and simple out of spec i2c message detection.
    Too much work is likely being done in the i2c message handler which can result in a visible backlog of key press events, or at least that is what I assume is happening
2024-06-30 introduce keyboard double buffer
    use a double buffer to prevent possible conflict in keybuffer. should add 0 - 1 frame of latency
2024-08-25 Initial Hori Track support
    Basic Hori Track support implemented
    Updated wiring guides
2024-08-27 Hori Track options
    introduce Hori Track switch options
    new full feature test build
2024-09-24 import pico-pio-usb
2024-09-29 rename usbhost -> i2chost
    With onboard usb, usbhost is now poorly named. Rename it more descriptively
2024-09-30 fix famikey+hori
    force the SM to output the data onto the pins as well, rather than including that in the loop, because otherwise we need to wait on both output enables and we don't have the spare SMs for that
    [usb2famikb.c]
2024-10-04 refactor and fix keycode releases
    function renames
    fix how keyboard key releases is detected and some minor mouse update
    [pico-usb2famikb.c, usb2famikb.c]
2024-10-22 reference pcb added
    [usb2famikb_full.kicad_pcb]
2024-11-30 clearly name gerber zip file
2024-12-14 build with led disabled for pico-w type boards
2024-12-30 referencepcb docs and license updates
    more information for reference PCB wiring and config
    consolidate software licenses
2025-01-07 1.0.1 updates
    support for pico-w (experimental)
    reduced pico overclock
    keyboard modifier key handling (ctrl, shift, alt, meta)
2025-01-16 #4 Improve NES state handling
    State of NES outputs cannot be trusted when interface starts or resets.
    Interface will now enter output monitoring properly regardless of high or low states.
    [usb2famikb.c]
2025-01-18 #4 Fix Family Basic Keyboard
    Fixed output when disabled (no longer interfere with controller input)
    Rearranged Family Basic Keyboard mapping to better fit US keyboard layout
    Removed old testapps and unnecessary pullups
    [pico-usb2famikb.c, usb2famikb.c]
